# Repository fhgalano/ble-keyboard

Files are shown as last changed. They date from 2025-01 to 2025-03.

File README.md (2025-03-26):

# Overview 

This is an implementation of a bluetooth keyboard on an ESP32-C3 Devkit

# Code 

This was developed in conjunction with [keyboard](https://github.com/fhgalano/keyboard)

I'm using [esp32-nimble](https://github.com/taks/esp32-nimble) to handle the bluetooth conection. Most of the bluetooth connection code is taken from the examples. 

# Mechanical

I've been having fun with kicad scripting - I like the consistency it creates. It also helps with the tedious parts of routing a bunch of keyboard keys. Feel free to check it out [here](https://github.com/fhgalano/kicad-utilities), but I would describe the code as 'certified jank'

The PCB for the keyboard is reversible and uses cherry mx compatible hotswap sockets. It uses most of the gpio pins available on the devkit, but any remaining pins are made available through jst ph-k through hole connectors. It's also only two layers to make it cheaper to iterate through.

_**as of Feb 2025 I have only just placed the order for the first revision of the pcb, so I have no idea if it works. Use at your own risk. I'll update once I get it.**_

*Update: the board works but also has some large flaws - the biggest of which being that the devkit is positioned such that I need to remove several keys in order to program it. I'm lucky that I made this with hotswaps. I don't plan to update the board for a while, despite the flaws - I'll be implementing some new features (quick switching between bonded devices, power saving, using multiple devices as one wirelessly, layer indication leds, timers instead of blocking delays, and other stuff I notice while using it). Once those are done, then I'll look at redesigning the board*

I plan to make documentation eventually, since it's good practice. However, it isn't a huge priority since I am literally the only person aware that this project exists. Also, anyone looking to make a keyboard should probably be using something more feature rich like QMK, RMK, or Keyberon. Nevertheless, if documentation would help your project/learning then I'd be happy to add it in.

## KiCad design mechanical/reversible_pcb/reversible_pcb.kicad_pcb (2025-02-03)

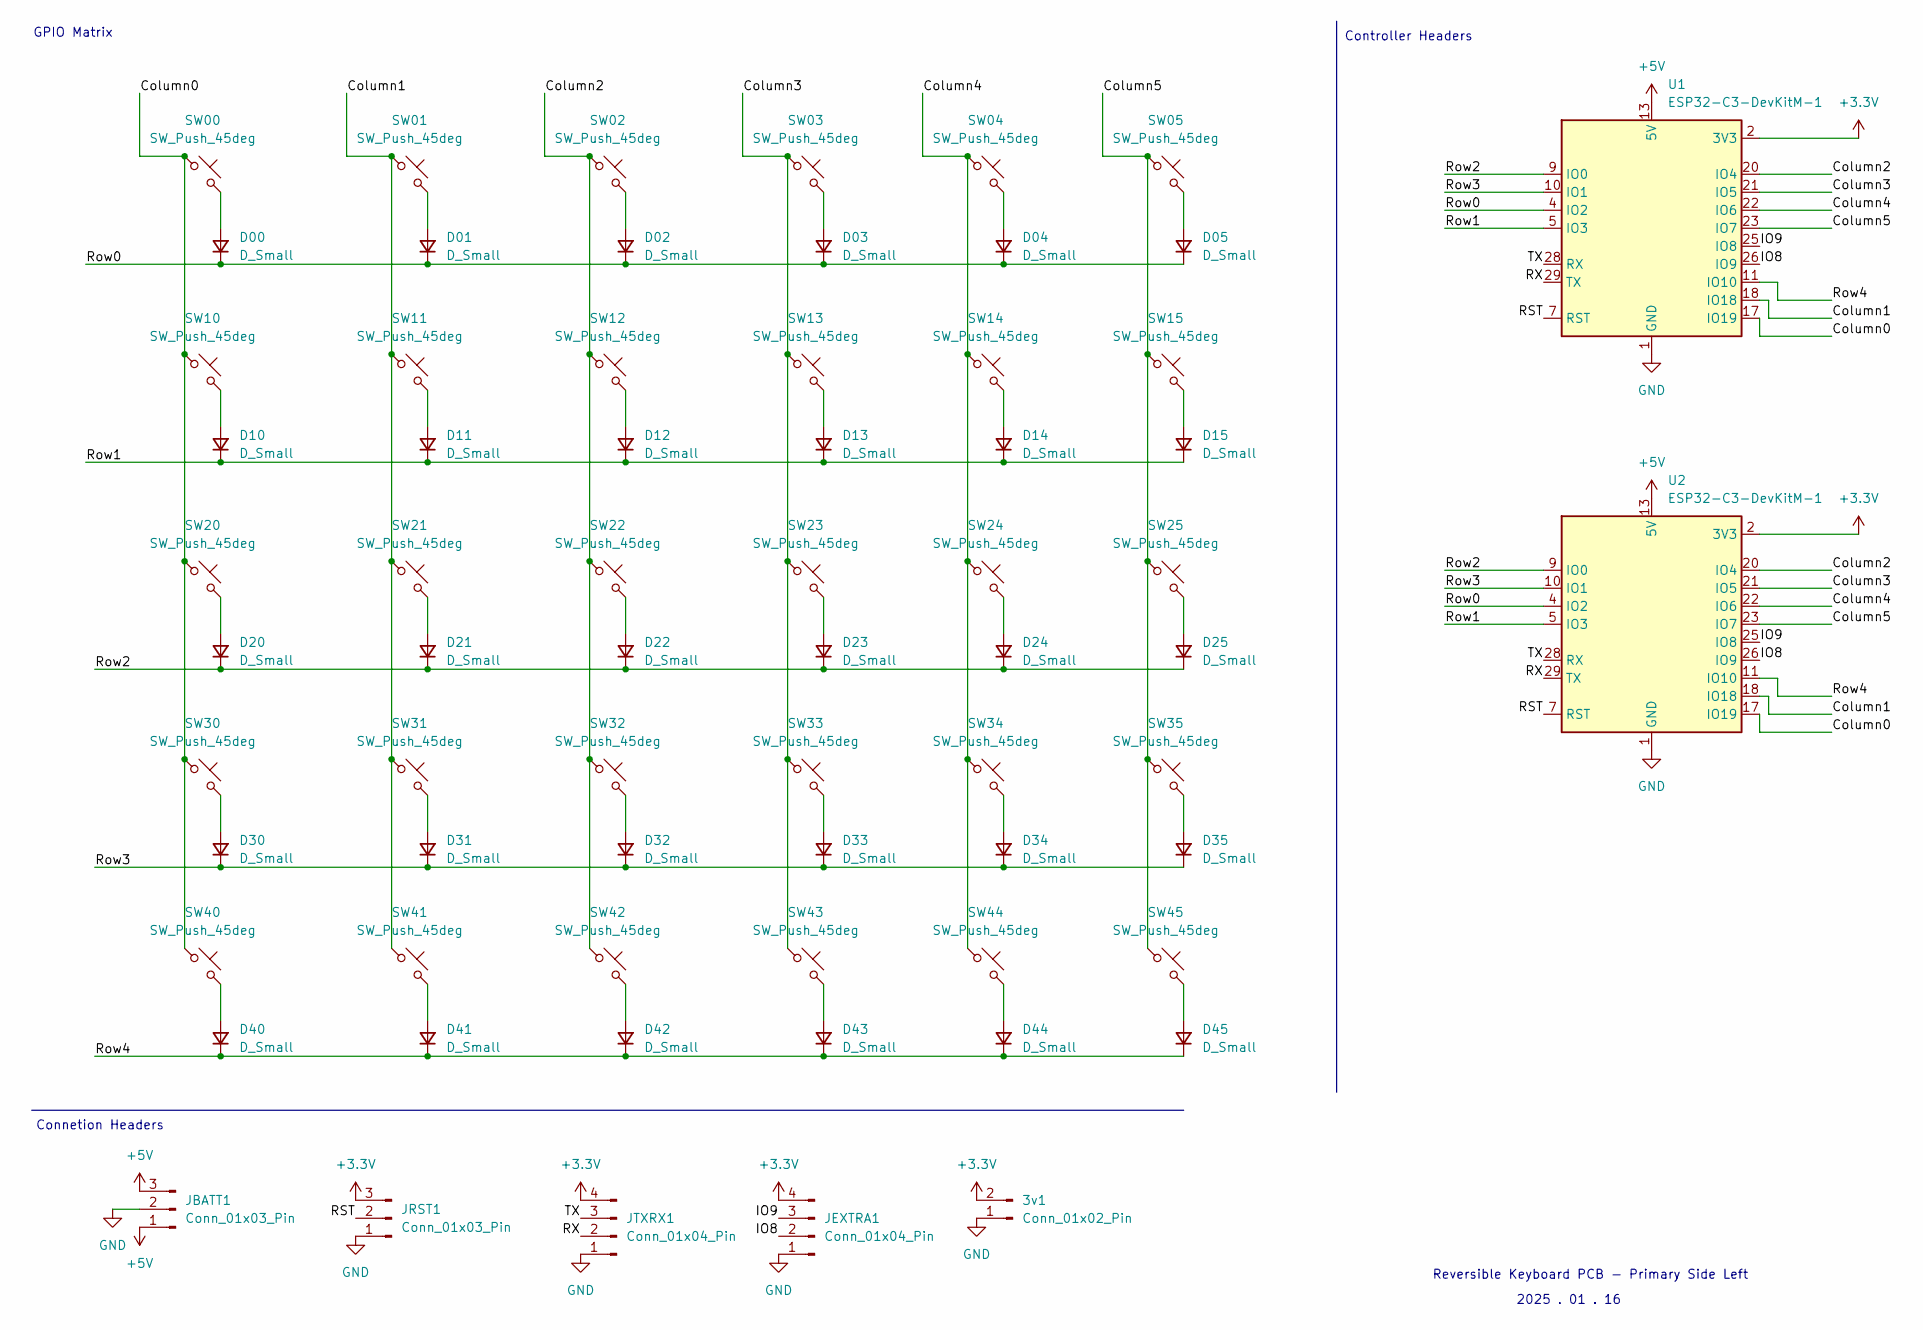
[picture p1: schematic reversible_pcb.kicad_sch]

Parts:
3v1: Conn_01x02_Pin; JST_PH_S2B-PH-K_1x02_P2.00mm_Horizontal
D00, D01, D02, D03, D04, D05, D10, D11, D12, D13, D14, D15, D20, D21, D22, D23, D24, D25, D30, D31, D32, D33, D34, D35, D40, D41, D42, D43, D44, D45: D_Small; D_T-1_P5.08mm_Horizontal_Double_Silkscreen
JBATT1: Conn_01x03_Pin; JST_PH_S3B-PH-K_1x03_P2.00mm_Horizontal
JEXTRA1: Conn_01x04_Pin; JST_PH_S4B-PH-K_1x04_P2.00mm_Horizontal
JRST1: Conn_01x03_Pin; JST_PH_S3B-PH-K_1x03_P2.00mm_Horizontal
JTXRX1: Conn_01x04_Pin; JST_PH_S4B-PH-K_1x04_P2.00mm_Horizontal
SW00, SW01, SW02, SW03, SW04, SW10, SW11, SW12, SW13, SW14, SW20, SW21, SW22, SW23, SW24, SW30, SW31, SW32, SW33, SW34, SW40, SW41, SW43, SW44, SW45: SW_Push_45deg; SW_Hotswap_Kailh_MX_reversible_1.00u
SW05, SW15, SW25, SW35: SW_Push_45deg; SW_Hotswap_Kailh_MX_reversible_1.25u
SW42: SW_Push_45deg; SW_Hotswap_Kailh_MX_reversible_1.50u_90deg
U1, U2: ESP32-C3-DevKitM-1

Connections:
+3.3V: 3v1.2, JEXTRA1.4, JRST1.3, JTXRX1.4, U1.2 (3V3), U1.3 (3V3), U2.2 (3V3), U2.3 (3V3)
+5V: JBATT1.1, JBATT1.3, U1.13 (5V), U1.14 (5V), U2.13 (5V), U2.14 (5V)
/Column0: SW00.1, SW10.1, SW20.1, SW30.1, SW40.1, U1.17 (IO19), U2.17 (IO19)
/Column1: SW01.1, SW11.1, SW21.1, SW31.1, SW41.1, U1.18 (IO18), U2.18 (IO18)
/Column2: SW02.1, SW12.1, SW22.1, SW32.1, SW42.1, U1.20 (IO4), U2.20 (IO4)
/Column3: SW03.1, SW13.1, SW23.1, SW33.1, SW43.1, U1.21 (IO5), U2.21 (IO5)
/Column4: SW04.1, SW14.1, SW24.1, SW34.1, SW44.1, U1.22 (IO6), U2.22 (IO6)
/Column5: SW05.1, SW15.1, SW25.1, SW35.1, SW45.1, U1.23 (IO7), U2.23 (IO7)
/IO8: JEXTRA1.2, U1.26 (IO9), U2.26 (IO9)
/IO9: JEXTRA1.3, U1.25 (IO8), U2.25 (IO8)
/RST: JRST1.2, U1.7 (RST), U2.7 (RST)
/RX: JTXRX1.2, U1.29 (TX), U2.29 (TX)
/Row0: D00.1 (K), D01.1 (K), D02.1 (K), D03.1 (K), D04.1 (K), D05.1 (K), U1.4 (IO2), U2.4 (IO2)
/Row1: D10.1 (K), D11.1 (K), D12.1 (K), D13.1 (K), D14.1 (K), D15.1 (K), U1.5 (IO3), U2.5 (IO3)
/Row2: D20.1 (K), D21.1 (K), D22.1 (K), D23.1 (K), D24.1 (K), D25.1 (K), U1.9 (IO0), U2.9 (IO0)
/Row3: D30.1 (K), D31.1 (K), D32.1 (K), D33.1 (K), D34.1 (K), D35.1 (K), U1.10 (IO1), U2.10 (IO1)
/Row4: D40.1 (K), D41.1 (K), D42.1 (K), D43.1 (K), D44.1 (K), D45.1 (K), U1.11 (IO10), U2.11 (IO10)
/TX: JTXRX1.3, U1.28 (RX), U2.28 (RX)
GND: 3v1.1, JBATT1.2, JEXTRA1.1, JRST1.1, JTXRX1.1, U1.1 (GND), U1.6 (GND), U1.8 (GND), U1.12 (GND), U1.15 (GND), U1.16 (GND), U1.19 (GND), U1.24 (GND), U1.27 (GND), U1.30 (GND), U2.1 (GND), U2.6 (GND), U2.8 (GND), U2.12 (GND), U2.15 (GND), U2.16 (GND), U2.19 (GND), U2.24 (GND), U2.27 (GND), U2.30 (GND)
unnamed: D00.2 (A), SW00.2
unnamed: D01.2 (A), SW01.2
unnamed: D02.2 (A), SW02.2
unnamed: D03.2 (A), SW03.2
unnamed: D04.2 (A), SW04.2
unnamed: D05.2 (A), SW05.2
unnamed: D10.2 (A), SW10.2
unnamed: D11.2 (A), SW11.2
unnamed: D12.2 (A), SW12.2
unnamed: D13.2 (A), SW13.2
unnamed: D14.2 (A), SW14.2
unnamed: D15.2 (A), SW15.2
unnamed: D20.2 (A), SW20.2
unnamed: D21.2 (A), SW21.2
unnamed: D22.2 (A), SW22.2
unnamed: D23.2 (A), SW23.2
unnamed: D24.2 (A), SW24.2
unnamed: D25.2 (A), SW25.2
unnamed: D30.2 (A), SW30.2
unnamed: D31.2 (A), SW31.2
unnamed: D32.2 (A), SW32.2
unnamed: D33.2 (A), SW33.2
unnamed: D34.2 (A), SW34.2
unnamed: D35.2 (A), SW35.2
unnamed: D40.2 (A), SW40.2
unnamed: D41.2 (A), SW41.2
unnamed: D42.2 (A), SW42.2
unnamed: D43.2 (A), SW43.2
unnamed: D44.2 (A), SW44.2
unnamed: D45.2 (A), SW45.2

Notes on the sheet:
Reversible Keyboard PCB - Primary Side Left
2025 . 01 . 16
Connetion Headers
Controller Headers
GPIO Matrix

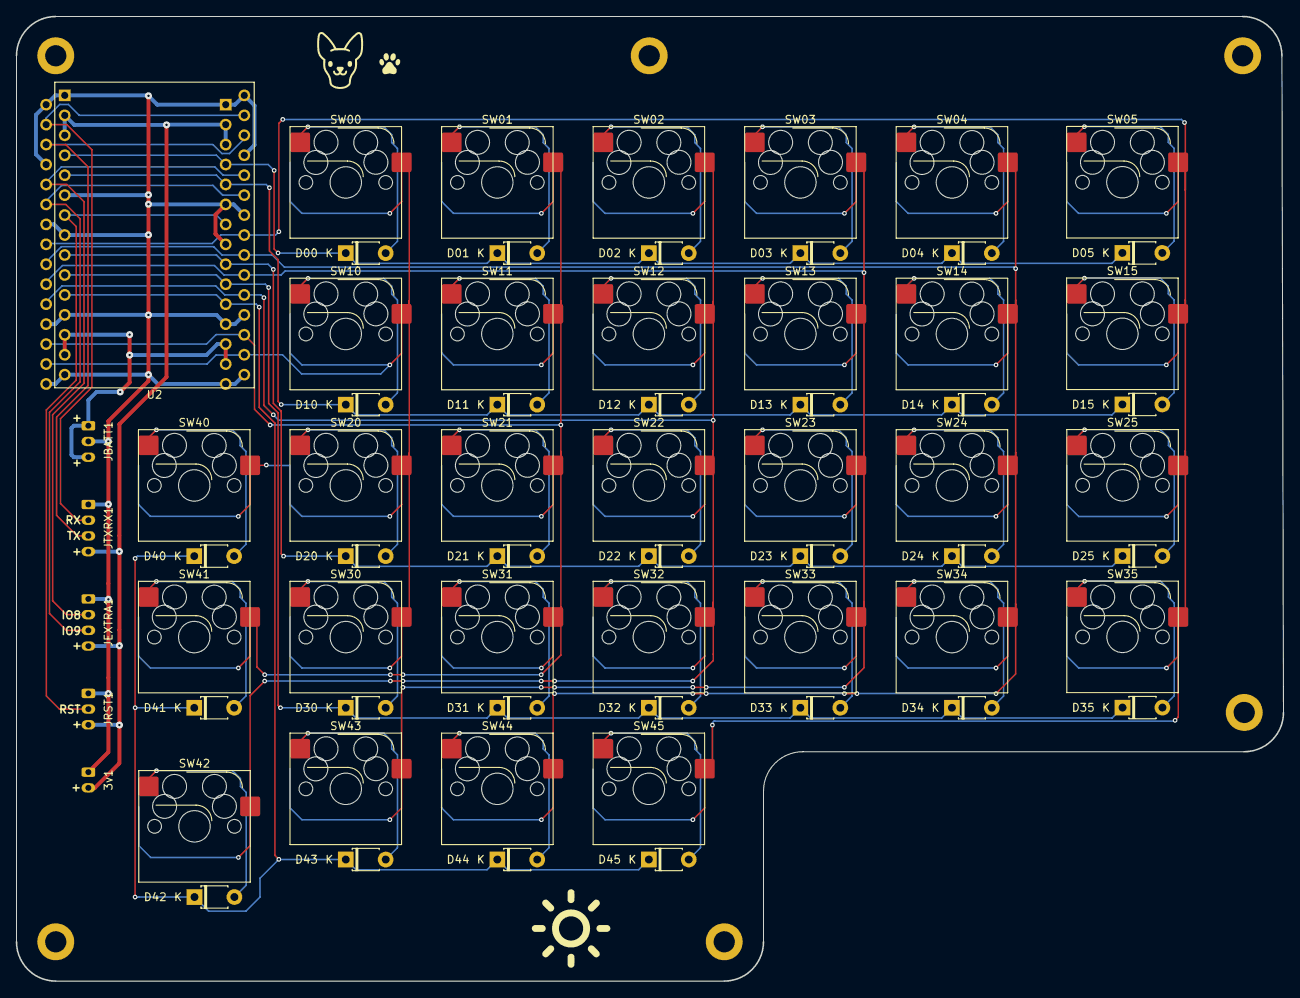
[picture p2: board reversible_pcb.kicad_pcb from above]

Board: 2 copper layers, 161.3 x 122.8 mm, 67 parts (1 on the bottom side), 49 nets.

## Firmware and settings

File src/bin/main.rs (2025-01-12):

// originally: https://github.com/T-vK/ESP32-BLE-Keyboard
#![allow(dead_code)]

use esp32_nimble::{
  enums::*, hid::*, utilities::mutex::Mutex, BLEAdvertisementData, BLECharacteristic, BLEDevice,
  BLEHIDDevice, BLEServer,
};
use std::sync::Arc;
use zerocopy::IntoBytes;
use zerocopy_derive::{Immutable, IntoBytes};

const KEYBOARD_ID: u8 = 0x01;
const MEDIA_KEYS_ID: u8 = 0x02;

const HID_REPORT_DISCRIPTOR: &[u8] = hid!(
  (USAGE_PAGE, 0x01), // USAGE_PAGE (Generic Desktop Ctrls)
  (USAGE, 0x06),      // USAGE (Keyboard)
  (COLLECTION, 0x01), // COLLECTION (Application)
  // ------------------------------------------------- Keyboard
  // Modifiers
  (REPORT_ID, KEYBOARD_ID), //   REPORT_ID (1)
  (USAGE_PAGE, 0x07),       //   USAGE_PAGE (Kbrd/Keypad)
  (USAGE_MINIMUM, 0xE0),    //   USAGE_MINIMUM (0xE0)
  (USAGE_MAXIMUM, 0xE7),    //   USAGE_MAXIMUM (0xE7)
  (LOGICAL_MINIMUM, 0x00),  //   LOGICAL_MINIMUM (0)
  (LOGICAL_MAXIMUM, 0x01),  //   Logical Maximum (1)
  (REPORT_SIZE, 0x01),      //   REPORT_SIZE (1)
  (REPORT_COUNT, 0x08),     //   REPORT_COUNT (8)
  (HIDINPUT, 0x02), //   INPUT (Data,Var,Abs,No Wrap,Linear,Preferred State,No Null Position)
                    //
  // Reserved  
  (REPORT_COUNT, 0x01), //   REPORT_COUNT (1) ; 1 byte (Reserved)
  (REPORT_SIZE, 0x08), //   REPORT_SIZE (8)
  (HIDINPUT, 0x01), //   INPUT (Const,Array,Abs,No Wrap,Linear,Preferred State,No Null Position)
                    //
  // LEDs
  (REPORT_COUNT, 0x05), //   REPORT_COUNT (5) ; 5 bits (Num lock, Caps lock, Scroll lock, Compose, Kana)
  (REPORT_SIZE, 0x01),  //   REPORT_SIZE (1)
  (USAGE_PAGE, 0x08),   //   USAGE_PAGE (LEDs)
  (USAGE_MINIMUM, 0x01), //   USAGE_MINIMUM (0x01) ; Num Lock
  (USAGE_MAXIMUM, 0x05), //   USAGE_MAXIMUM (0x05) ; Kana
  (HIDOUTPUT, 0x02), //   OUTPUT (Data,Var,Abs,No Wrap,Linear,Preferred State,No Null Position,Non-volatile)
  // Padding
  (REPORT_COUNT, 0x01), //   REPORT_COUNT (1) ; 3 bits (Padding)
  (REPORT_SIZE, 0x03), //   REPORT_SIZE (3)
  (HIDOUTPUT, 0x01), //   OUTPUT (Const,Array,Abs,No Wrap,Linear,Preferred State,No Null Position,Non-volatile)
                        
  // Keys
  (REPORT_COUNT, 0x06), //   REPORT_COUNT (6) ; 6 bytes (Keys)
  (REPORT_SIZE, 0x08), //   REPORT_SIZE(8)
  (LOGICAL_MINIMUM, 0x00), //   LOGICAL_MINIMUM(0)
  (LOGICAL_MAXIMUM, 0x65), //   LOGICAL_MAXIMUM(0x65) ; 101 keys
  (USAGE_PAGE, 0x07), //   USAGE_PAGE (Kbrd/Keypad)
  (USAGE_MINIMUM, 0x00), //   USAGE_MINIMUM (0)
  (USAGE_MAXIMUM, 0x65), //   USAGE_MAXIMUM (0x65)
  (HIDINPUT, 0x00),  //   INPUT (Data,Array,Abs,No Wrap,Linear,Preferred State,No Null Position)
  (END_COLLECTION),  // END_COLLECTION
  // ------------------------------------------------- Media Keys
  (USAGE_PAGE, 0x0C),         // USAGE_PAGE (Consumer)
  (USAGE, 0x01),              // USAGE (Consumer Control)
  (COLLECTION, 0x01),         // COLLECTION (Application)
  (REPORT_ID, MEDIA_KEYS_ID), //   REPORT_ID (3)
  (USAGE_PAGE, 0x0C),         //   USAGE_PAGE (Consumer)
  (LOGICAL_MINIMUM, 0x00),    //   LOGICAL_MINIMUM (0)
  (LOGICAL_MAXIMUM, 0x01),    //   LOGICAL_MAXIMUM (1)
  (REPORT_SIZE, 0x01),        //   REPORT_SIZE (1)
  (REPORT_COUNT, 0x10),       //   REPORT_COUNT (16)
  (USAGE, 0xB5),              //   USAGE (Scan Next Track)     ; bit 0: 1
  (USAGE, 0xB6),              //   USAGE (Scan Previous Track) ; bit 1: 2
  (USAGE, 0xB7),              //   USAGE (Stop)                ; bit 2: 4
  (USAGE, 0xCD),              //   USAGE (Play/Pause)          ; bit 3: 8
  (USAGE, 0xE2),              //   USAGE (Mute)                ; bit 4: 16
  (USAGE, 0xE9),              //   USAGE (Volume Increment)    ; bit 5: 32
  (USAGE, 0xEA),              //   USAGE (Volume Decrement)    ; bit 6: 64
  (USAGE, 0x23, 0x02),        //   Usage (WWW Home)            ; bit 7: 128
  (USAGE, 0x94, 0x01),        //   Usage (My Computer) ; bit 0: 1
  (USAGE, 0x92, 0x01),        //   Usage (Calculator)  ; bit 1: 2
  (USAGE, 0x2A, 0x02),        //   Usage (WWW fav)     ; bit 2: 4
  (USAGE, 0x21, 0x02),        //   Usage (WWW search)  ; bit 3: 8
  (USAGE, 0x26, 0x02),        //   Usage (WWW stop)    ; bit 4: 16
  (USAGE, 0x24, 0x02),        //   Usage (WWW back)    ; bit 5: 32
  (USAGE, 0x83, 0x01),        //   Usage (Media sel)   ; bit 6: 64
  (USAGE, 0x8A, 0x01),        //   Usage (Mail)        ; bit 7: 128
  (HIDINPUT, 0x02), // INPUT (Data,Var,Abs,No Wrap,Linear,Preferred State,No Null Position)
  (END_COLLECTION), // END_COLLECTION
);

const SHIFT: u8 = 0x80;
const ASCII_MAP: &[u8] = &[
  0x00,         // NUL
  0x00,         // SOH
  0x00,         // STX
  0x00,         // ETX
  0x00,         // EOT
  0x00,         // ENQ
  0x00,         // ACK
  0x00,         // BEL
  0x2a,         // BS	Backspace
  0x2b,         // TAB	Tab
  0x28,         // LF	Enter
  0x00,         // VT
  0x00,         // FF
  0x00,         // CR
  0x00,         // SO
  0x00,         // SI
  0x00,         // DEL
  0x00,         // DC1
  0x00,         // DC2
  0x00,         // DC3
  0x00,         // DC4
  0x00,         // NAK
  0x00,         // SYN
  0x00,         // ETB
  0x00,         // CAN
  0x00,         // EM
  0x00,         // SUB
  0x00,         // ESC
  0x00,         // FS
  0x00,         // GS
  0x00,         // RS
  0x00,         // US
  0x2c,         //  ' '
  0x1e | SHIFT, // !
  0x34 | SHIFT, // "
  0x20 | SHIFT, // #
  0x21 | SHIFT, // $
  0x22 | SHIFT, // %
  0x24 | SHIFT, // &
  0x34,         // '
  0x26 | SHIFT, // (
  0x27 | SHIFT, // )
  0x25 | SHIFT, // *
  0x2e | SHIFT, // +
  0x36,         // ,
  0x2d,         // -
  0x37,         // .
  0x38,         // /
  0x27,         // 0
  0x1e,         // 1
  0x1f,         // 2
  0x20,         // 3
  0x21,         // 4
  0x22,         // 5
  0x23,         // 6
  0x24,         // 7
  0x25,         // 8
  0x26,         // 9
  0x33 | SHIFT, // :
  0x33,         // ;
  0x36 | SHIFT, // <
  0x2e,         // =
  0x37 | SHIFT, // >
  0x38 | SHIFT, // ?
  0x1f | SHIFT, // @
  0x04 | SHIFT, // A
  0x05 | SHIFT, // B
  0x06 | SHIFT, // C
  0x07 | SHIFT, // D
  0x08 | SHIFT, // E
  0x09 | SHIFT, // F
  0x0a | SHIFT, // G
  0x0b | SHIFT, // H
  0x0c | SHIFT, // I
  0x0d | SHIFT, // J
  0x0e | SHIFT, // K
  0x0f | SHIFT, // L
  0x10 | SHIFT, // M
  0x11 | SHIFT, // N
  0x12 | SHIFT, // O
  0x13 | SHIFT, // P
  0x14 | SHIFT, // Q
  0x15 | SHIFT, // R
  0x16 | SHIFT, // S
  0x17 | SHIFT, // T
  0x18 | SHIFT, // U
  0x19 | SHIFT, // V
  0x1a | SHIFT, // W
  0x1b | SHIFT, // X
  0x1c | SHIFT, // Y
  0x1d | SHIFT, // Z
  0x2f,         // [
  0x31,         // bslash
  0x30,         // ]
  0x23 | SHIFT, // ^
  0x2d | SHIFT, // _
  0x35,         // `
  0x04,         // a
  0x05,         // b
  0x06,         // c
  0x07,         // d
  0x08,         // e
  0x09,         // f
  0x0a,         // g
  0x0b,         // h
  0x0c,         // i
  0x0d,         // j
  0x0e,         // k
  0x0f,         // l
  0x10,         // m
  0x11,         // n
  0x12,         // o
  0x13,         // p
  0x14,         // q
  0x15,         // r
  0x16,         // s
  0x17,         // t
  0x18,         // u
  0x19,         // v
  0x1a,         // w
  0x1b,         // x
  0x1c,         // y
  0x1d,         // z
  0x2f | SHIFT, // {
  0x31 | SHIFT, // |
  0x30 | SHIFT, // }
  0x35 | SHIFT, // ~
  0,            // DEL
];

#[derive(IntoBytes, Immutable)]
#[repr(packed)]
struct KeyReport {
  modifiers: u8,
  reserved: u8,
  keys: [u8; 6],
}

struct Keyboard {
  server: &'static mut BLEServer,
  input_keyboard: Arc<Mutex<BLECharacteristic>>,
  output_keyboard: Arc<Mutex<BLECharacteristic>>,
  input_media_keys: Arc<Mutex<BLECharacteristic>>,
  key_report: KeyReport,
}

impl Keyboard {
  fn new() -> anyhow::Result<Self> {
    let device = BLEDevice::take();
    device
      .security()
      .set_auth(AuthReq::all())
      .set_io_cap(SecurityIOCap::NoInputNoOutput)
      .resolve_rpa();

    let server = device.get_server();
    let mut hid = BLEHIDDevice::new(server);

    let input_keyboard = hid.input_report(KEYBOARD_ID);
    let output_keyboard = hid.output_report(KEYBOARD_ID);
    let input_media_keys = hid.input_report(MEDIA_KEYS_ID);

    hid.manufacturer("Espressif");
    hid.pnp(0x02, 0x05ac, 0x820a, 0x0210);
    hid.hid_info(0x00, 0x01);

    hid.report_map(HID_REPORT_DISCRIPTOR);

    hid.set_battery_level(100);

    let ble_advertising = device.get_advertising();
    ble_advertising.lock().scan_response(false).set_data(
      BLEAdvertisementData::new()
        .name("ESP32 Keyboard")
        .appearance(0x03C1)
        .add_service_uuid(hid.hid_service().lock().uuid()),
    )?;
    ble_advertising.lock().start()?;

    Ok(Self {
      server,
      input_keyboard,
      output_keyboard,
      input_media_keys,
      key_report: KeyReport {
        modifiers: 0,
        reserved: 0,
        keys: [0; 6],
      },
    })
  }

  fn connected(&self) -> bool {
    self.server.connected_count() > 0
  }

  fn write(&mut self, str: &str) {
    for char in str.as_bytes() {
      self.press(*char);
      self.release();
    }
  }

  fn press(&mut self, char: u8) {
    let mut key = ASCII_MAP[char as usize];
    if (key & SHIFT) > 0 {
      self.key_report.modifiers |= 0x02;
      key &= !SHIFT;
    }
    self.key_report.keys[0] = key;
    self.send_report(&self.key_report);
  }

  fn release(&mut self) {
    self.key_report.modifiers = 0;
    self.key_report.keys.fill(0);
    self.send_report(&self.key_report);
  }

  fn send_report(&self, keys: &KeyReport) {
    self
      .input_keyboard
      .lock()
      .set_value(keys.as_bytes())
      .notify();
    esp_idf_svc::hal::delay::Ets::delay_ms(7);
  }
}

fn main() -> anyhow::Result<()> {
  esp_idf_svc::sys::link_patches();
  esp_idf_svc::log::EspLogger::initialize_default();

  let mut keyboard = Keyboard::new()?;

  loop {
    if keyboard.connected() {
      ::log::info!("Sending 'Hello world'...");
      keyboard.write("Hello world\n");
    }
    esp_idf_svc::hal::delay::FreeRtos::delay_ms(5000);
  }
}

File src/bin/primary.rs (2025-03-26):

// originally: https://github.com/T-vK/ESP32-BLE-Keyboard
#![allow(dead_code)]

// std
use std::collections::HashMap;
use std::ops::Mul;
use std::sync::{Arc, Mutex as StdMutex};

// external crates
use esp_idf_svc::hal::peripherals::*;
use esp_idf_svc::hal::task::block_on;
use esp32_nimble::{
  enums::*, hid::*, utilities::mutex::Mutex, BLEAdvertisementData, BLECharacteristic, BLEDevice,
  BLEHIDDevice, BLEScan, BLEServer, NimbleProperties, uuid128,
};
use zerocopy::{FromBytes, IntoBytes, transmute};

// local dependencies
use keyboard::{ Key, Keyboard, KeyCombo, Layer, layer, Matrix, MatrixLoc2};

// local
use ble_kdb_rs::{GpioMatrix, PhantomMatrix};
use ble_kdb_rs::WirelessKeyboard;
use ble_kdb_rs::WirelessMatrix;
use ble_kdb_rs::MultiMatrix;


fn main() -> anyhow::Result<()> {
    esp_idf_svc::sys::link_patches();
    esp_idf_svc::log::EspLogger::initialize_default();
    
    let mut args: Vec<String> = std::env::args().collect();
    let keymap_variant = args.pop().unwrap_or("right".to_string());

    let peripherals = Peripherals::take()?;

    let rows = vec![
	  peripherals.pins.gpio2.into(),
	  peripherals.pins.gpio3.into(),
	  peripherals.pins.gpio0.into(),
	  peripherals.pins.gpio1.into(),
	  peripherals.pins.gpio10.into(),
    ];

    let columns = vec![
	  peripherals.pins.gpio19.into(),
	  peripherals.pins.gpio18.into(),
	  peripherals.pins.gpio4.into(),
	  peripherals.pins.gpio5.into(),
	  peripherals.pins.gpio6.into(),
	  peripherals.pins.gpio7.into(),
    ];
    
    let service_uuid = uuid128!("9410d4c1-bf2e-490c-821f-56d4f1a0e2d4");

    block_on(async {
        let gpio_matrix = GpioMatrix::new(rows, columns);
        let phantom_matrix = PhantomMatrix::new();
        ::log::info!("created gpio matrix...");
        let internal_keyboard = Keyboard::new(Box::new(phantom_matrix), key_map("big_mode"), mod_map());
        ::log::info!("created internal keyboard");
        let mut wireless_keyboard = WirelessKeyboard::new(internal_keyboard, Some(keymap_variant))?;
        if let Ok(mut wireless_matrix) = WirelessMatrix::new().await {
            let wm = Arc::new(StdMutex::new(wireless_matrix));
            let matrix = MultiMatrix::new_from_two(gpio_matrix, wm.clone());

            let overwrite_internal_keyboard = Keyboard::new(
                Box::new(matrix), key_map("big_mode"), mod_map()
            );

            wireless_keyboard.keyboard = overwrite_internal_keyboard;

            loop {
                if wireless_keyboard.connected() {
                    //::log::info!("wireless pos: {:?}", wireless_matrix.poll());
                    wireless_keyboard.poll_and_send();
                    //::log::info!("virtual_pos: {:?}", virtual_pos);
                }
                //let virtual_pos = matrix_loc_characteristic.read_value().await?;
                //::log::info!("virtual_pos: {:?}", virtual_pos);
                esp_idf_svc::hal::delay::FreeRtos::delay_ms(30);
            }

        };

        loop {
            if wireless_keyboard.connected() {
                wireless_keyboard.poll_and_send();
            }
            ::log::info!("In fallback loop");
            esp_idf_svc::hal::delay::FreeRtos::delay_ms(30);
        }

    })

}

fn key_map(variant: &str) -> HashMap<KeyCombo, Layer> {
    match variant {
        "right" => {
            let base_map = layer!(
                [Key::SIX_HAT, Key::SEVEN_AMPERSAND, Key::EIGHT_STAR, Key::NINE_LPARENTHESIS, Key::ZERO_RPARENTHESIS, Key::BACKSPACE],
                [Key::Yy, Key::Uu, Key::Ii, Key::Oo, Key::Pp, Key::DASH_UNDERSCORE],
                [Key::Hh, Key::Jj, Key::Kk, Key::Ll, Key::SEMICOLON_COLON, Key::SQUOTE_DQUOTE],
                [Key::Nn, Key::Mm, Key::COMMA_LANGLE, Key::PERIOD_RANGLE, Key::FSLASH_QUESTION, Key::ENTER],
                [Key::BACKSPACE, Key::BSLASH_BAR, Key::NOKEY, Key::SPACE, Key::NOKEY, Key::EQUALS_PLUS],
            );
            let paw_map = layer!(
                [Key::NOKEY, Key::NOKEY, Key::NOKEY, Key::NOKEY, Key::NOKEY, Key::PRINT_SCREEN],
                [Key::NOKEY, Key::NOKEY, Key::NOKEY, Key::LSQUARE_LCURLY, Key::RSQUARE_RCURYLY, Key::NOKEY],
                [Key::LEFT,  Key::DOWN, Key::RIGHT, Key::UP, Key::NOKEY, Key::NOKEY],
                [Key::NOKEY, Key::NOKEY, Key::NOKEY, Key::NOKEY, Key::NOKEY, Key::NOKEY],
                [Key::NOKEY, Key::NOKEY, Key::NOKEY, Key::NOKEY, Key::NOKEY, Key::NOKEY],
            );

            let mut big_map = HashMap::new();
            big_map.insert(KeyCombo::default(), base_map);
            big_map.insert(KeyCombo::new(&[Key::PAW]), paw_map);

            big_map
        },
        "big_mode" => {
            let base_map = layer!(
                [
                    Key::SIX_HAT, Key::SEVEN_AMPERSAND, Key::EIGHT_STAR, Key::NINE_LPARENTHESIS, Key::ZERO_RPARENTHESIS, Key::BACKSPACE,
                    Key::FIVE_PERCENT, Key::FOUR_DOLLAR, Key::THREE_HASH, Key::TWO_AT, Key::ONE_EXCLAMATION, Key::GRAVE_TILDE
                ],
                [
                    Key::Yy, Key::Uu, Key::Ii, Key::Oo, Key::Pp, Key::DASH_UNDERSCORE,
                    Key::Tt, Key::Rr, Key::Ee, Key::Ww, Key::Qq, Key::TAB
                ],
                [
                    Key::Hh, Key::Jj, Key::Kk, Key::Ll, Key::SEMICOLON_COLON, Key::SQUOTE_DQUOTE,
                    Key::Gg, Key::Ff, Key::Dd, Key::Ss, Key::Aa, Key::NOKEY
                ],
                [
                    Key::Nn, Key::Mm, Key::COMMA_LANGLE, Key::PERIOD_RANGLE, Key::FSLASH_QUESTION, Key::ENTER,
                    Key::Bb, Key::Vv, Key::Cc, Key::Xx, Key::Zz, Key::NOKEY
                ],
                [
                    Key::BACKSPACE, Key::BSLASH_BAR, Key::NOKEY, Key::SPACE, Key::NOKEY, Key::EQUALS_PLUS,
                    Key::NOKEY, Key::NOKEY, Key::ESCAPE, Key::SPACE, Key::NOKEY, Key::NOKEY
                ],
            );
            let paw_map = layer!(
                [Key::NOKEY, Key::NOKEY, Key::NOKEY, Key::NOKEY, Key::NOKEY, Key::PRINT_SCREEN],
                [Key::NOKEY, Key::NOKEY, Key::NOKEY, Key::LSQUARE_LCURLY, Key::RSQUARE_RCURYLY, Key::NOKEY],
                [Key::LEFT,  Key::DOWN, Key::RIGHT, Key::UP, Key::NOKEY, Key::NOKEY],
                [Key::NOKEY, Key::NOKEY, Key::NOKEY, Key::NOKEY, Key::NOKEY, Key::NOKEY],
                [Key::NOKEY, Key::NOKEY, Key::NOKEY, Key::NOKEY, Key::NOKEY, Key::NOKEY],
            );

            let mut big_map = HashMap::new();
            big_map.insert(KeyCombo::default(), base_map);

            big_map
        }
        _ => panic!("unknown keymap variant {}", variant),
    }
}

fn mod_map() -> Layer {
    let mut map = HashMap::new();
    // right side
    map.insert((4,2), Key::PAW);
    map.insert((4, 4), Key::RSHIFT);

    // left side
    map.insert((4,9), Key::LALT);
    map.insert((4,10), Key::LSUPER);
    map.insert((2,11), Key::LCTRL);
    map.insert((3,11), Key::LSHIFT);

    map
}

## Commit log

2025-01-12 initial commit; keyboard messages send correctly, but is not able to use gpio as input
    [lib.rs, main.rs, tests.rs]
2025-02-03 fixed polling logic issues
    [lib.rs]
2025-02-03 added kicad files for main board
    [reversible_pcb.kicad_pcb, reversible_pcb.kicad_sch]
2025-03-08 updated to use correct gpio pins from the pcb, also using new lib features to create layers
    [tests.rs]
2025-03-26 working (ugly) mvp for two keyboard halves acting as one device
